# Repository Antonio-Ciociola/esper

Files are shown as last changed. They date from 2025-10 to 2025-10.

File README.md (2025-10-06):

# Esper

An esp32 based eurorack module.

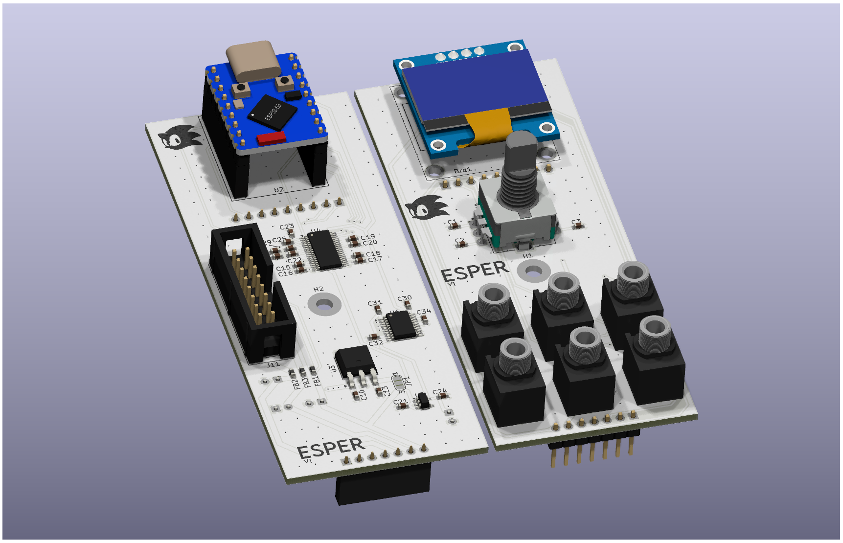
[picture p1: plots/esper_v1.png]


## Specifications

- 8HP width
- 4 CV inputs
- 2 Audio Outputs
- Oled Display with LVGL GUI
- Rotary Encoder with Push Button
- Esp32s3 has 2 cores, Bluetooth and Wifi support

## Photos





## Future Plans and Issues

- Better alternative to external adc for cv inputs
- Codec chip for both audio in and out, to allow for audio processing
- The esp32s3 floating point performance is not great

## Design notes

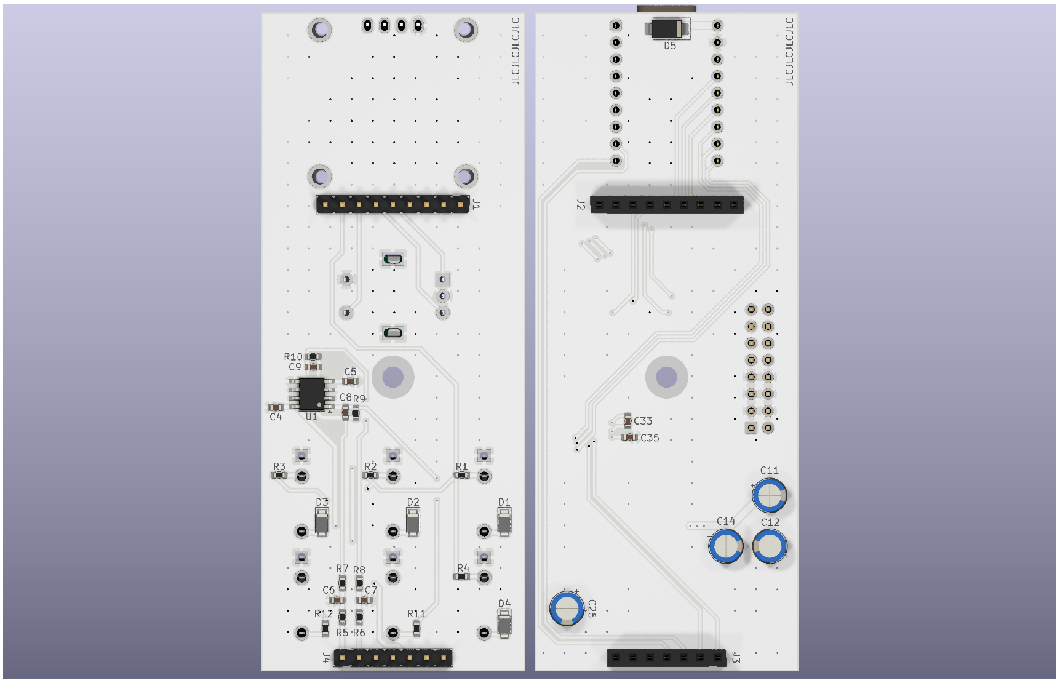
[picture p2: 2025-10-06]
plots/esper_v1_bottom.png

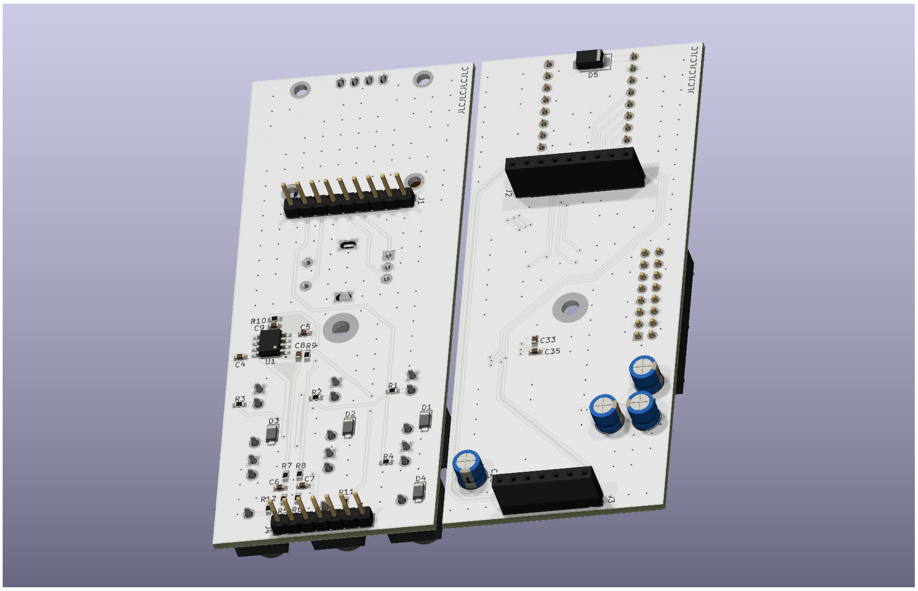
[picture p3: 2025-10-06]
plots/esper_v1_bottom_2.png

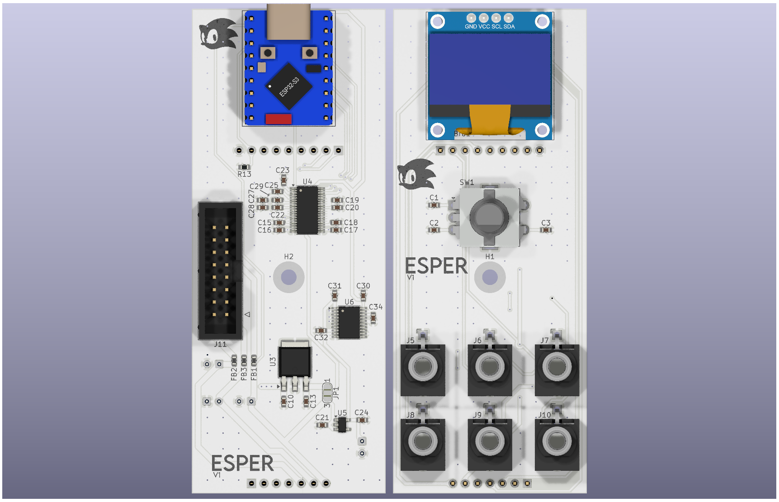
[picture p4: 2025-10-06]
plots/esper_v1_top.png

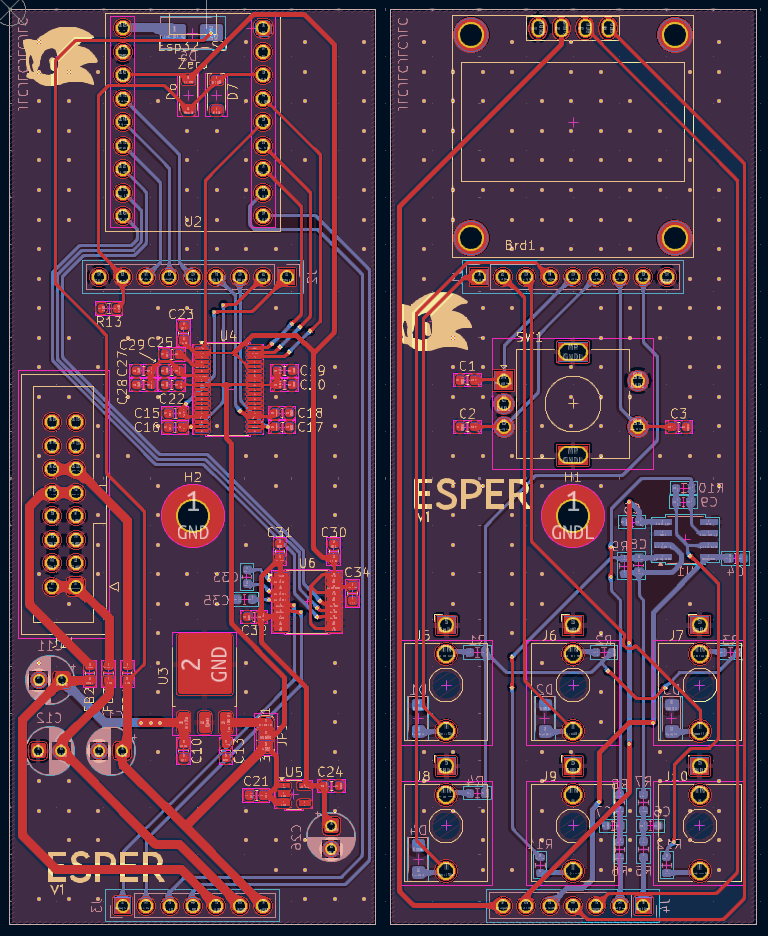
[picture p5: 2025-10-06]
plots/Pcb_screenshot.png

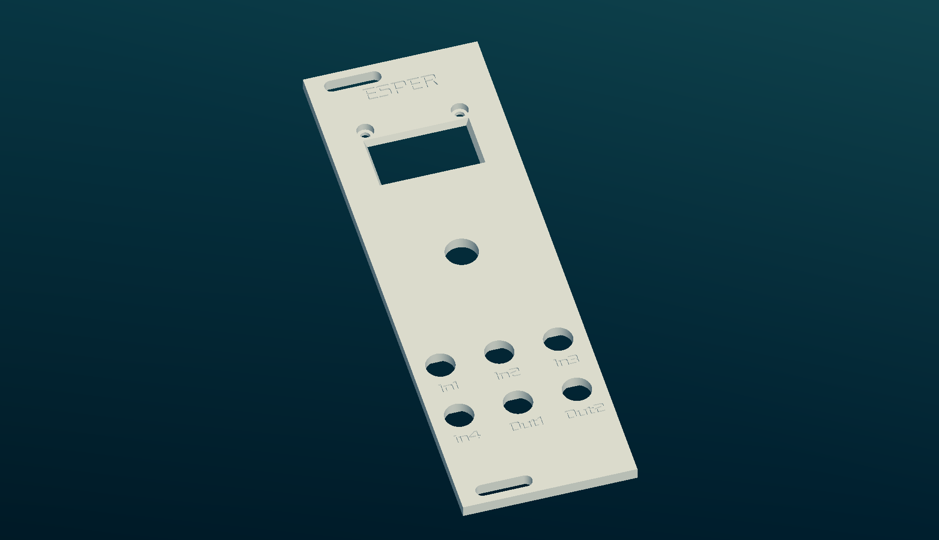
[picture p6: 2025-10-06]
panel/screenshot.png

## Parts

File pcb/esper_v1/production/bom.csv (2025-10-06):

Designator | Footprint | Quantity | Value | LCSC Part #
C10 | 0603 | 1 | 220n
C11, C12, C14, C26 | CP_Radial_D5.0mm_P2.50mm | 4 | 10u
C13, C21, C24, C30, C31, C32, C34 | 0603 | 7 | 100n
C15, C16, C17, C18 | 0603 | 4 | 1n
C19, C23, C25, C27, C28 | 0603 | 5 | 10u
C20, C22, C29 | 0603 | 3 | 1u
C33, C35 | 0603 | 2 | 2.2u
D5 | D_SMA | 1 | B340A
D6, D7 | D_SOD-123 | 2 | BAT43
FB1, FB2, FB3 | 0603 | 3 | BLM18R
J11 | IDC-Header_2x08_P2.54mm_Vertical | 1 | Conn_02x08_Odd_Even
J2 | PinSocket_1x09_P2.54mm_Vertical | 1 | m_in_Con
J3 | PinSocket_1x07_P2.54mm_Vertical | 1 | m_Out_Con
R13 | 0603 | 1 | _
U2 | Esp32-S3 Zero | 1 | ESP32_S3_zero
U3 | TO-252-3_TabPin2 | 1 | LM78M05_TO252
U4 | TSSOP-38_4.4x9.7mm_P0.5mm | 1 | ADS8688
U5 | SOT-23-5 | 1 | ME6211C33M5
U6 | TSSOP-20_4.4x6.5mm_P0.65mm | 1 | PCM5102A

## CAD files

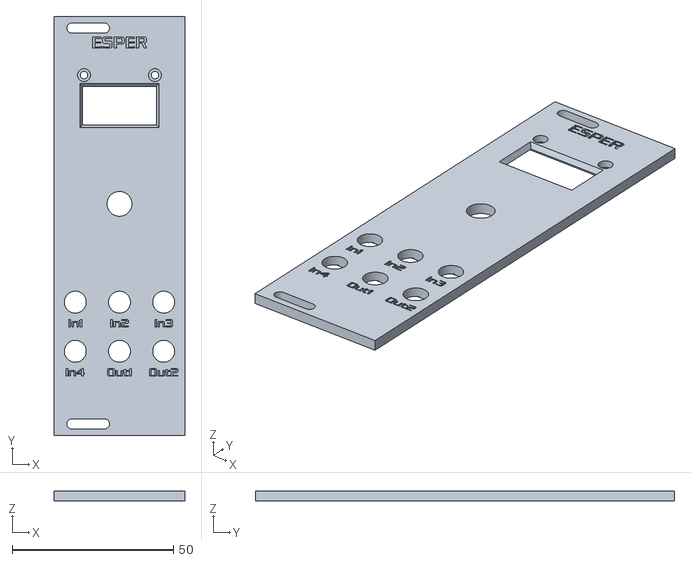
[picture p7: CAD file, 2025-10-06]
panel/esper.stl
40.6 x 130.0 x 3.00

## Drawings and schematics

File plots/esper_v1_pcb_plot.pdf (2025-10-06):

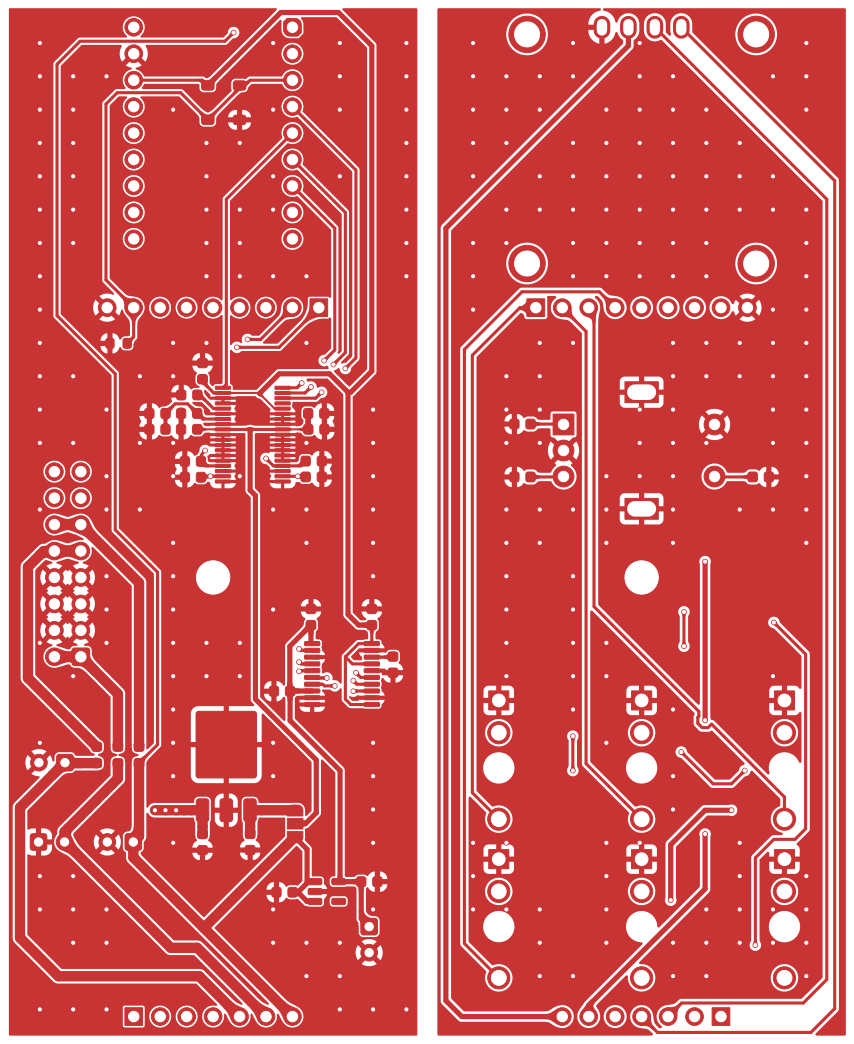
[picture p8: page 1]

Id: 1/9 Title: Esper File: esper_v1.kicad_pcb Sheet: Sonic803

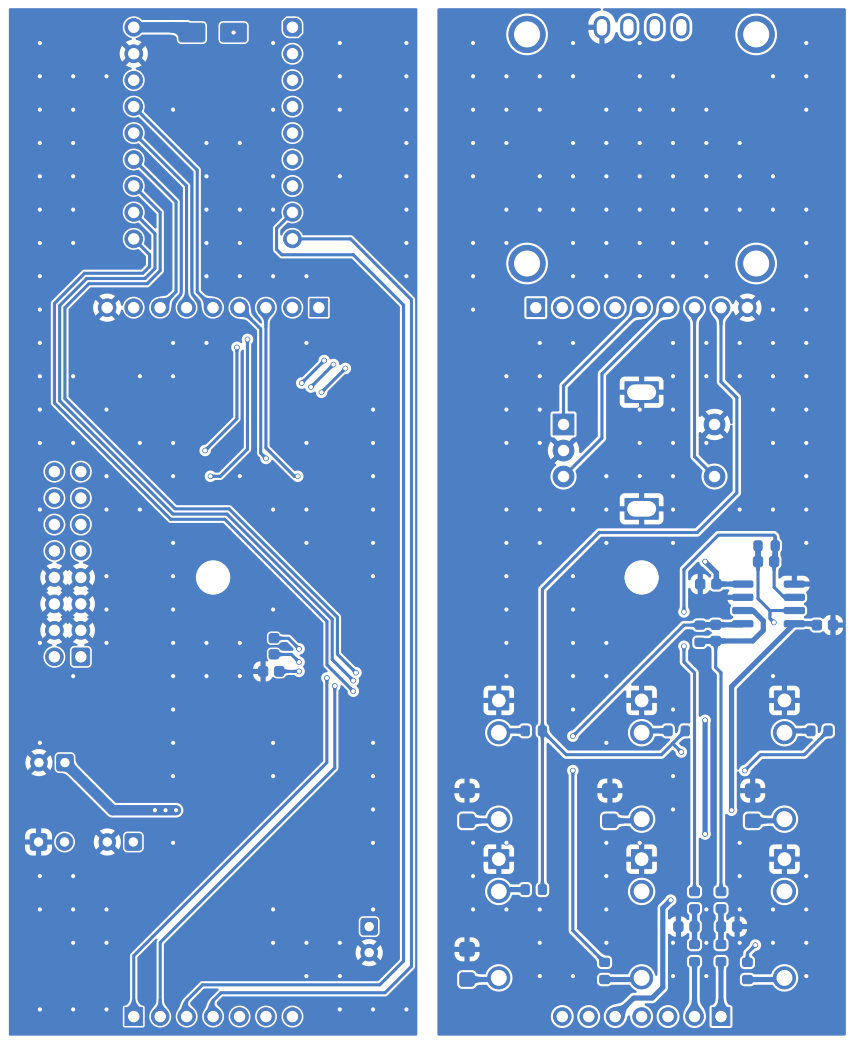
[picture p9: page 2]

Id: 2/9 Title: Esper File: esper_v1.kicad_pcb Sheet: Sonic803

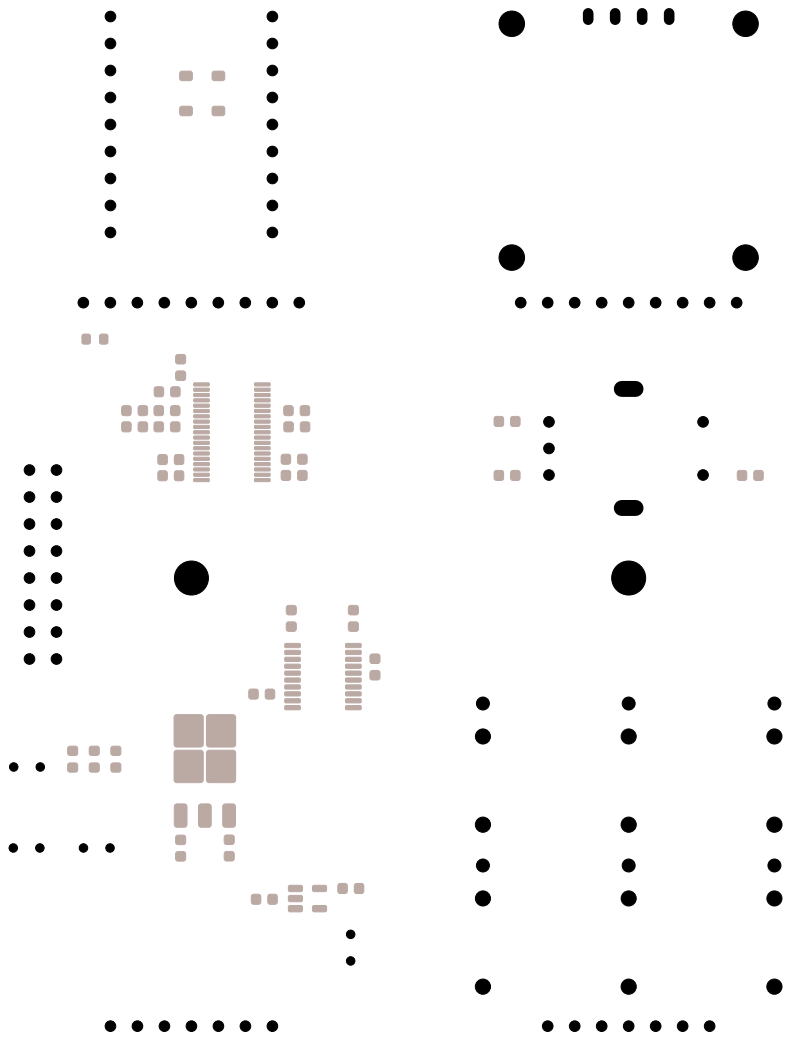
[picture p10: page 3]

Id: 3/9 Title: Esper File: esper_v1.kicad_pcb Sheet: Sonic803

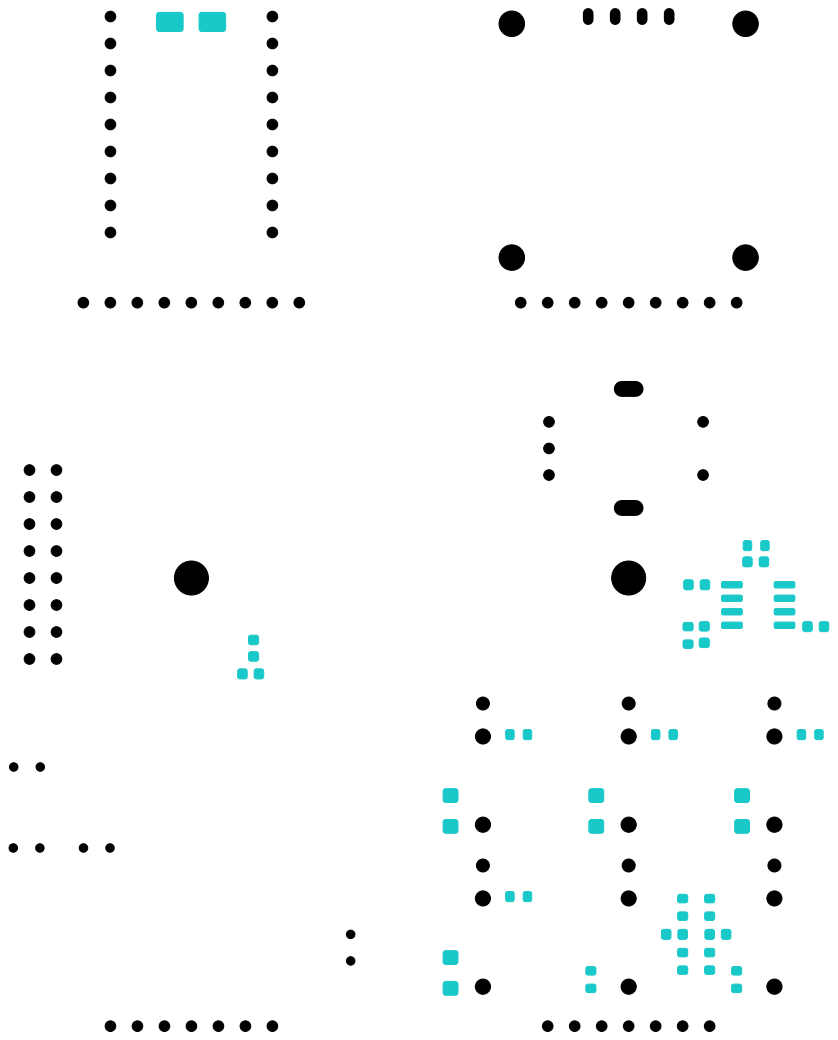
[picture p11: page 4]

Id: 4/9 Title: Esper File: esper_v1.kicad_pcb Sheet: Sonic803

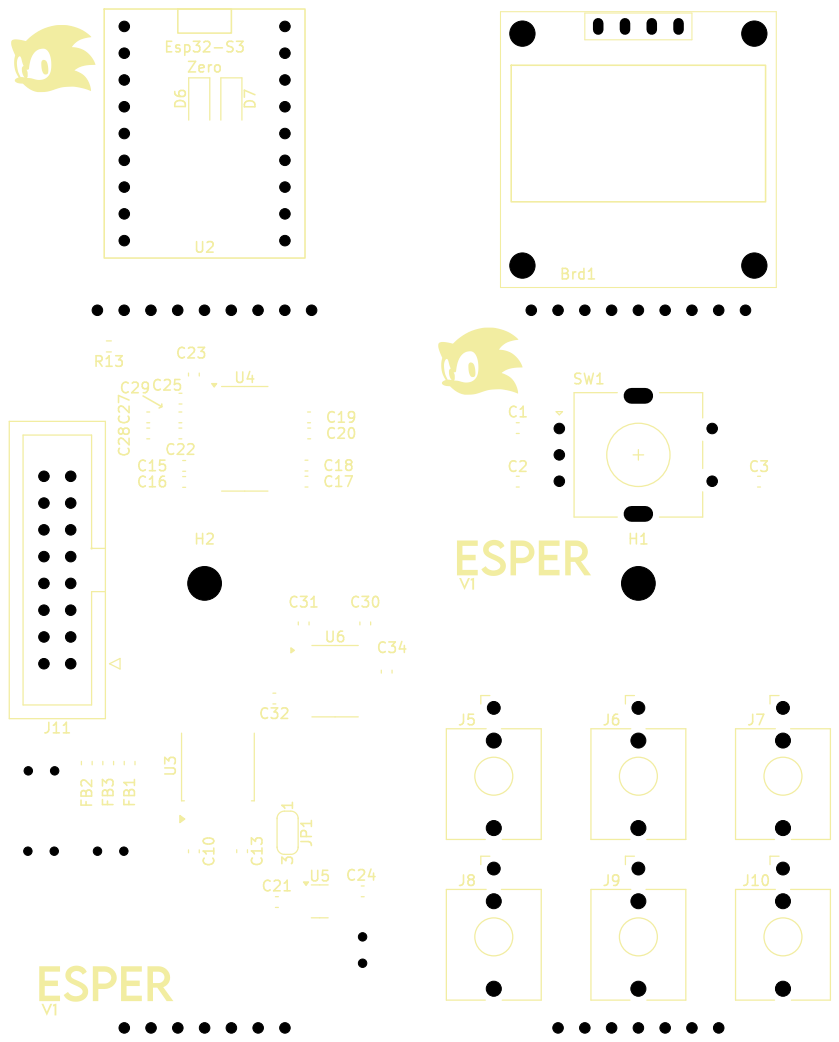
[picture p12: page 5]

Id: 5/9 Title: Esper File: esper_v1.kicad_pcb Sheet: Sonic803

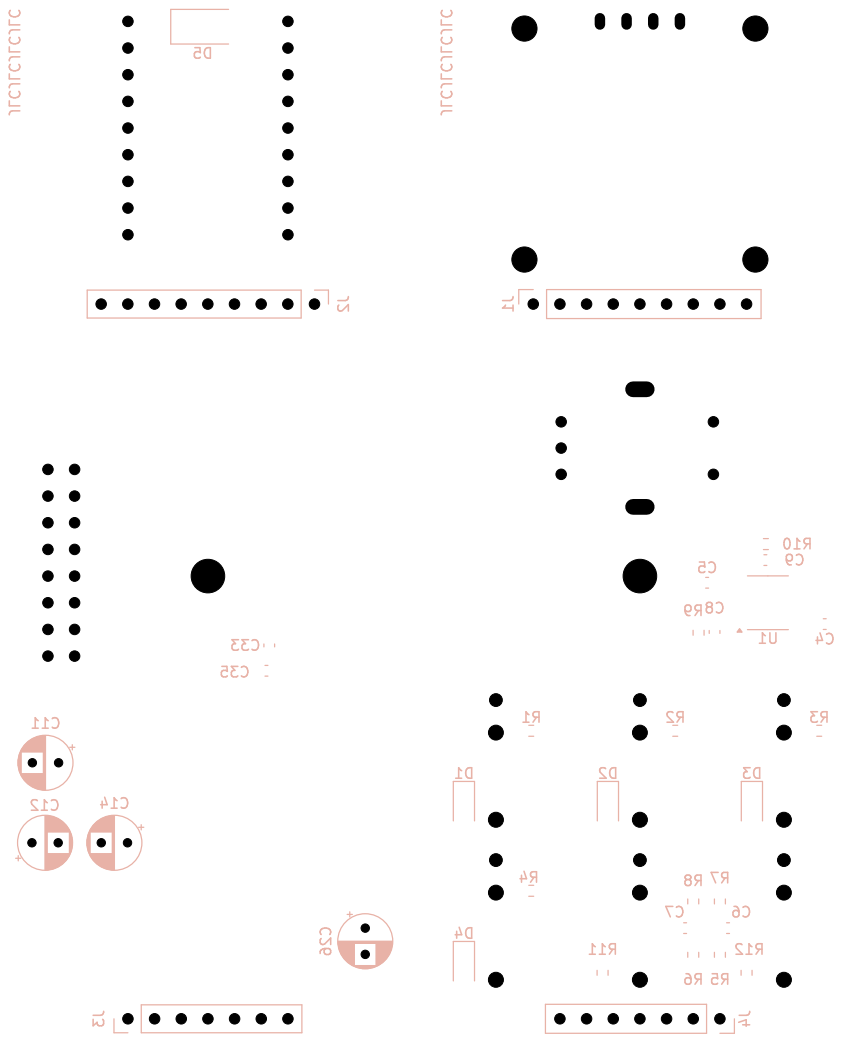
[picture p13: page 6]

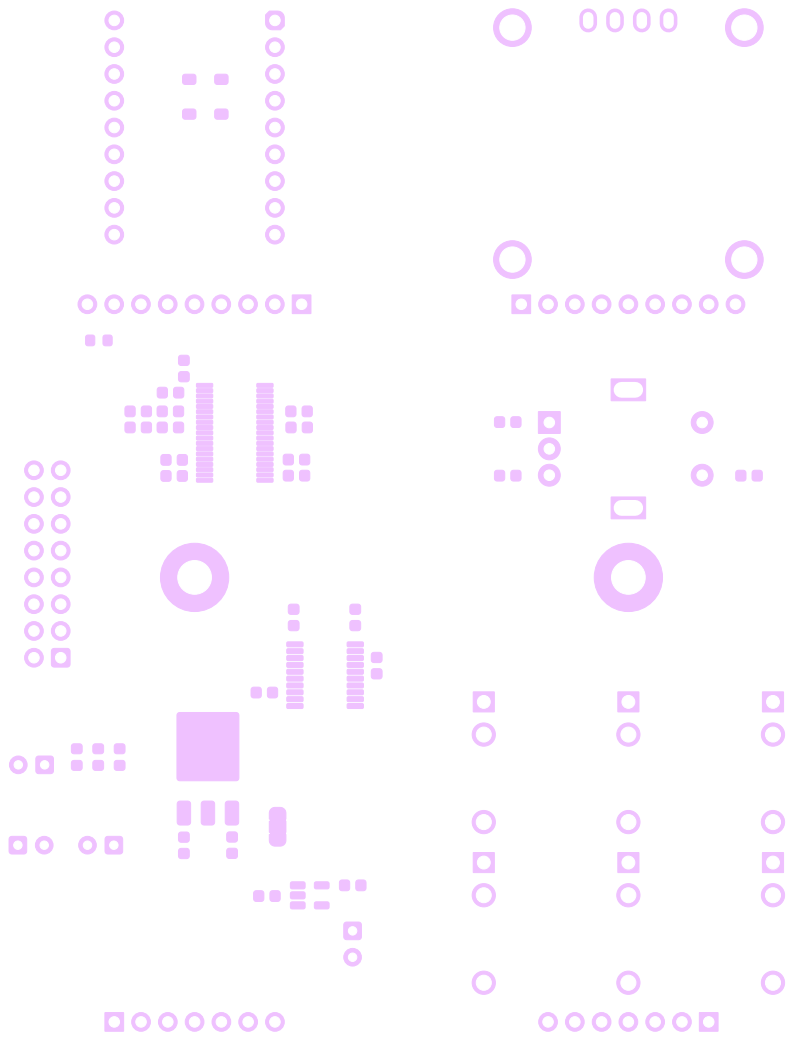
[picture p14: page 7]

Id: 7/9 Title: Esper File: esper_v1.kicad_pcb Sheet: Sonic803

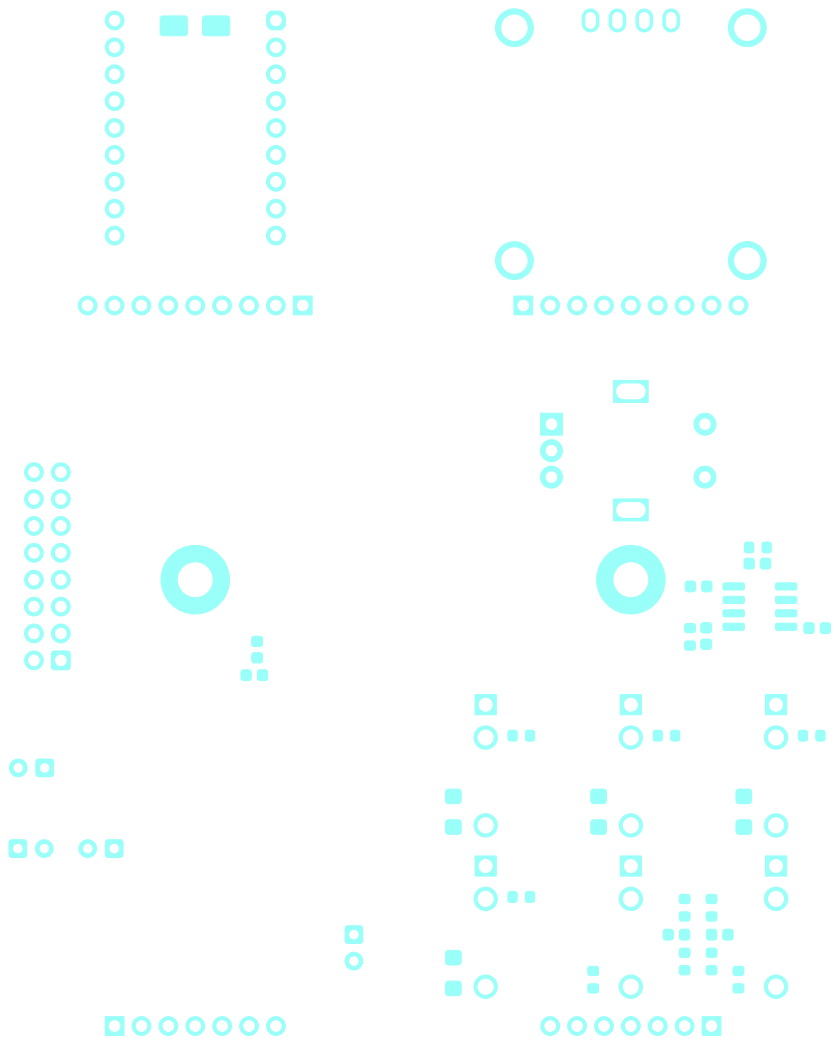
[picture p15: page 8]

Id: 8/9 Title: Esper File: esper_v1.kicad_pcb Sheet: Sonic803

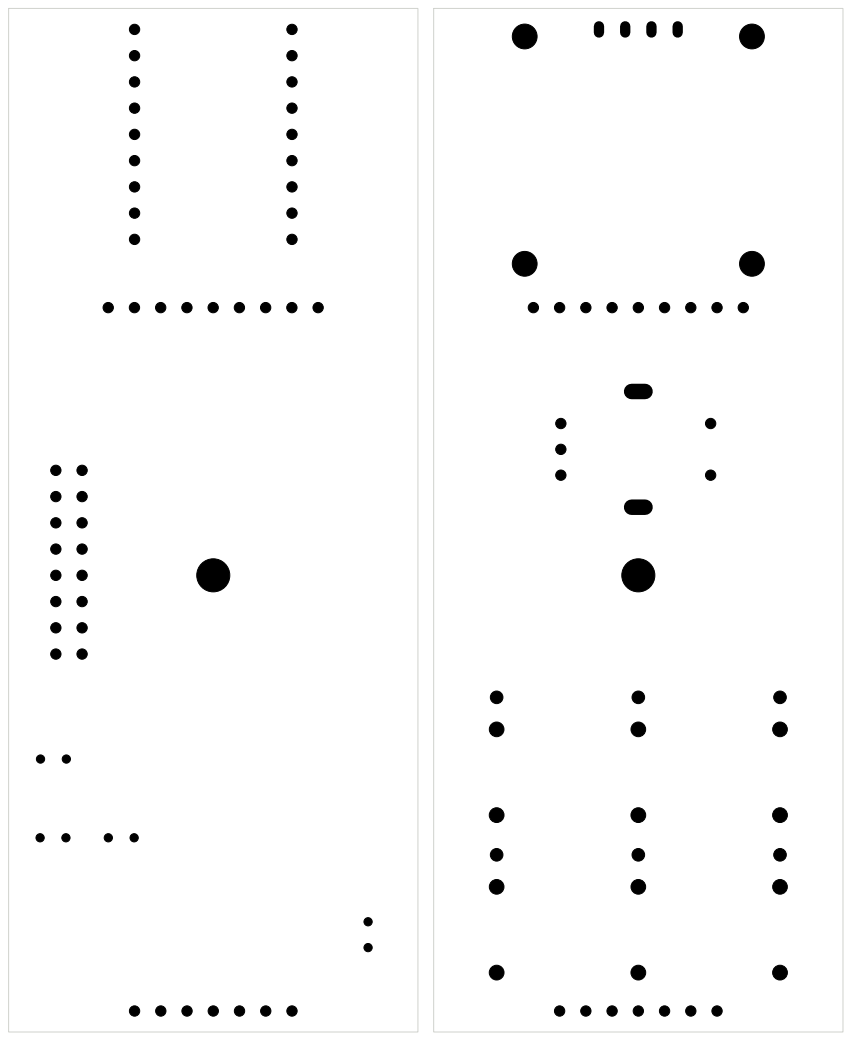
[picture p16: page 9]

Id: 9/9 Title: Esper File: esper_v1.kicad_pcb Sheet: Sonic803

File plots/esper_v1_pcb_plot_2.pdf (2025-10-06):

J8 U2 Esp32-S3 Zero C25 | U6
J9 C31 C29 | C17 R13 | C30 U4 C¹³ C22C23 1 | 2 | 3 | 4 | 5 | 6 1 | 2 | 3 | 4 | 5 | 6 ABCD | ABCD Date: 2025-05-13 KiCad | E.D.A. 9.0.4 Size: A4 | Rev: 1

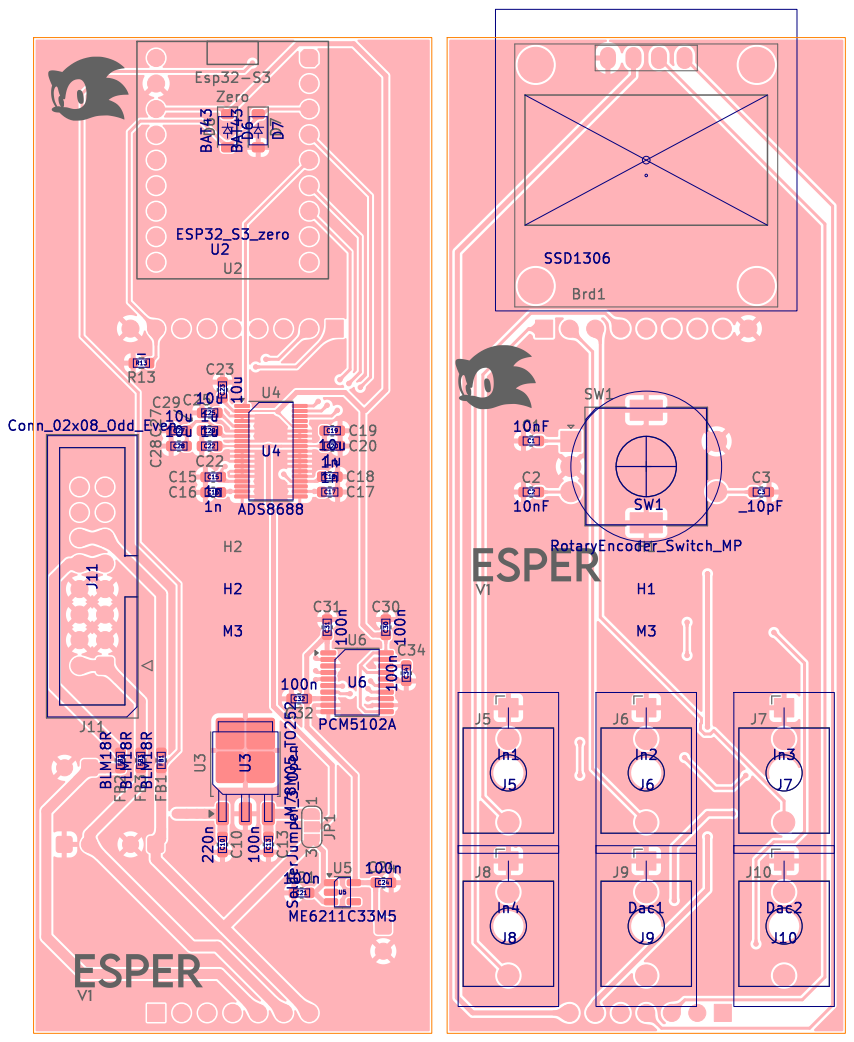
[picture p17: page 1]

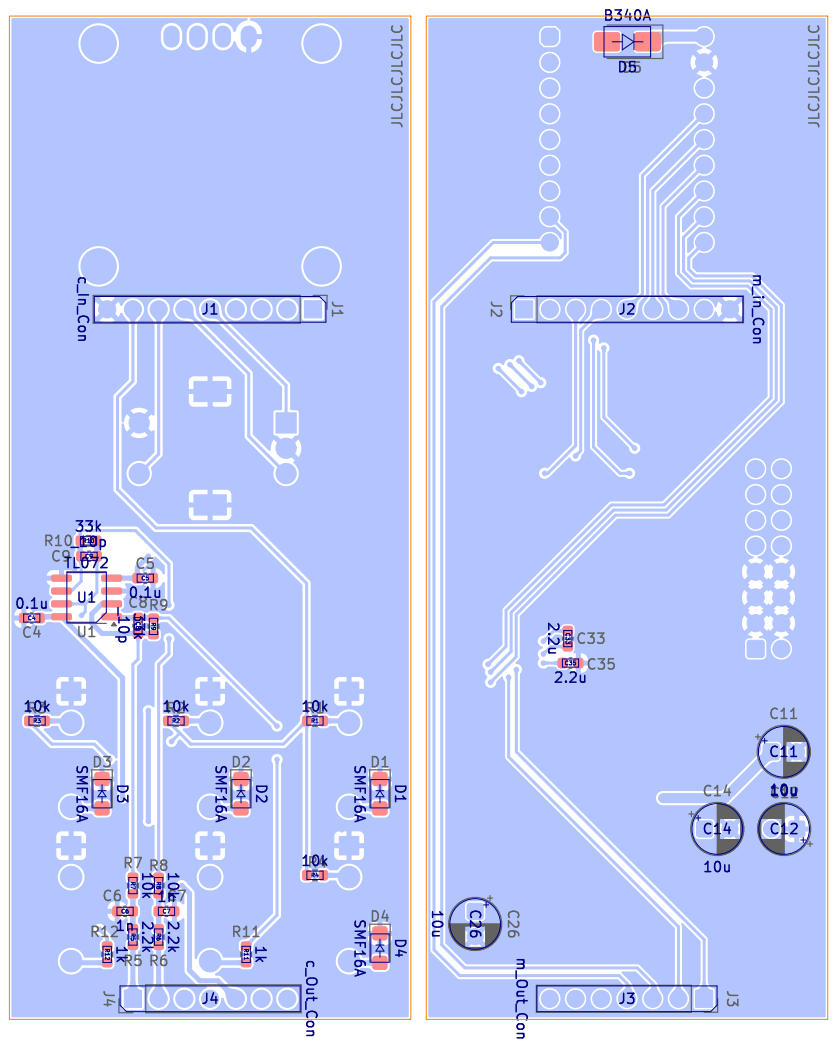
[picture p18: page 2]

JLCJLCJLCJLC JLCJLCJLCJLC J2 C7 R11 R1 C11 C14 C35 R9 D4 R10 C5 R12 C33 J3 D5 R4 C12 C9 C6 D1 R7 C4 D3 D2 R5C8 C26 U1 R2 J4 R6 R8 J1 R3 1 2 3 4 5 6 1 2 3 4 5 6 ABCD ABCD Date: 2025-05-13 KiCad E.D.A. 9.0.4 Size: A4 Rev: 1

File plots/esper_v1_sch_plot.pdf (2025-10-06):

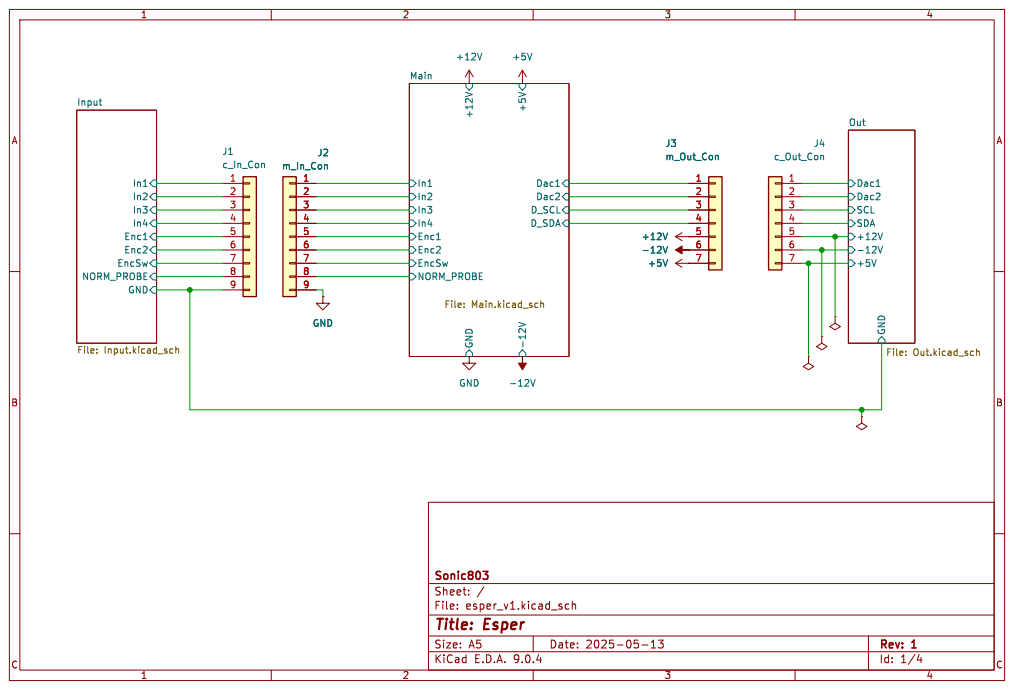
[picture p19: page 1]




2 VO 3 C10 220n GNDLH2 M3 +3.3V U2 ESP32_S3_zero GPIO1 15 GPIO2 14 GPIO3 13 GPIO4 12 GPIO5 11 GPIO6 10 RX 2 TX 1 VBus 18 GND 17 3V3 16 GPIO13 3 GPIO12 4 GPIO11 5 GPIO10 6 GPIO9 7 GPIO8 8 GPIO7 9 GNDL D5B340A U5 ME6211C33M5 V_{IN} 1 CE 3 V_{SS} 2 V_{OUT} 5 GNDL C24

9 OUTL 6 OUTR 7 CAPP 2 CAPM 4

8 AVDD 30 DVDD 34 DGND 33 SDO 36 SDI 1 SCLK 37 ~{CS} 38 DAISY 3 ~{RST/PD}2 ~{REFSEL}4 REFCAP 7 REFIO 5 REFGND 6 U4ADS8688

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

Id: 4/4 Title: Esper File: Main.kicad_sch Sheet: /Main/ Sonic803

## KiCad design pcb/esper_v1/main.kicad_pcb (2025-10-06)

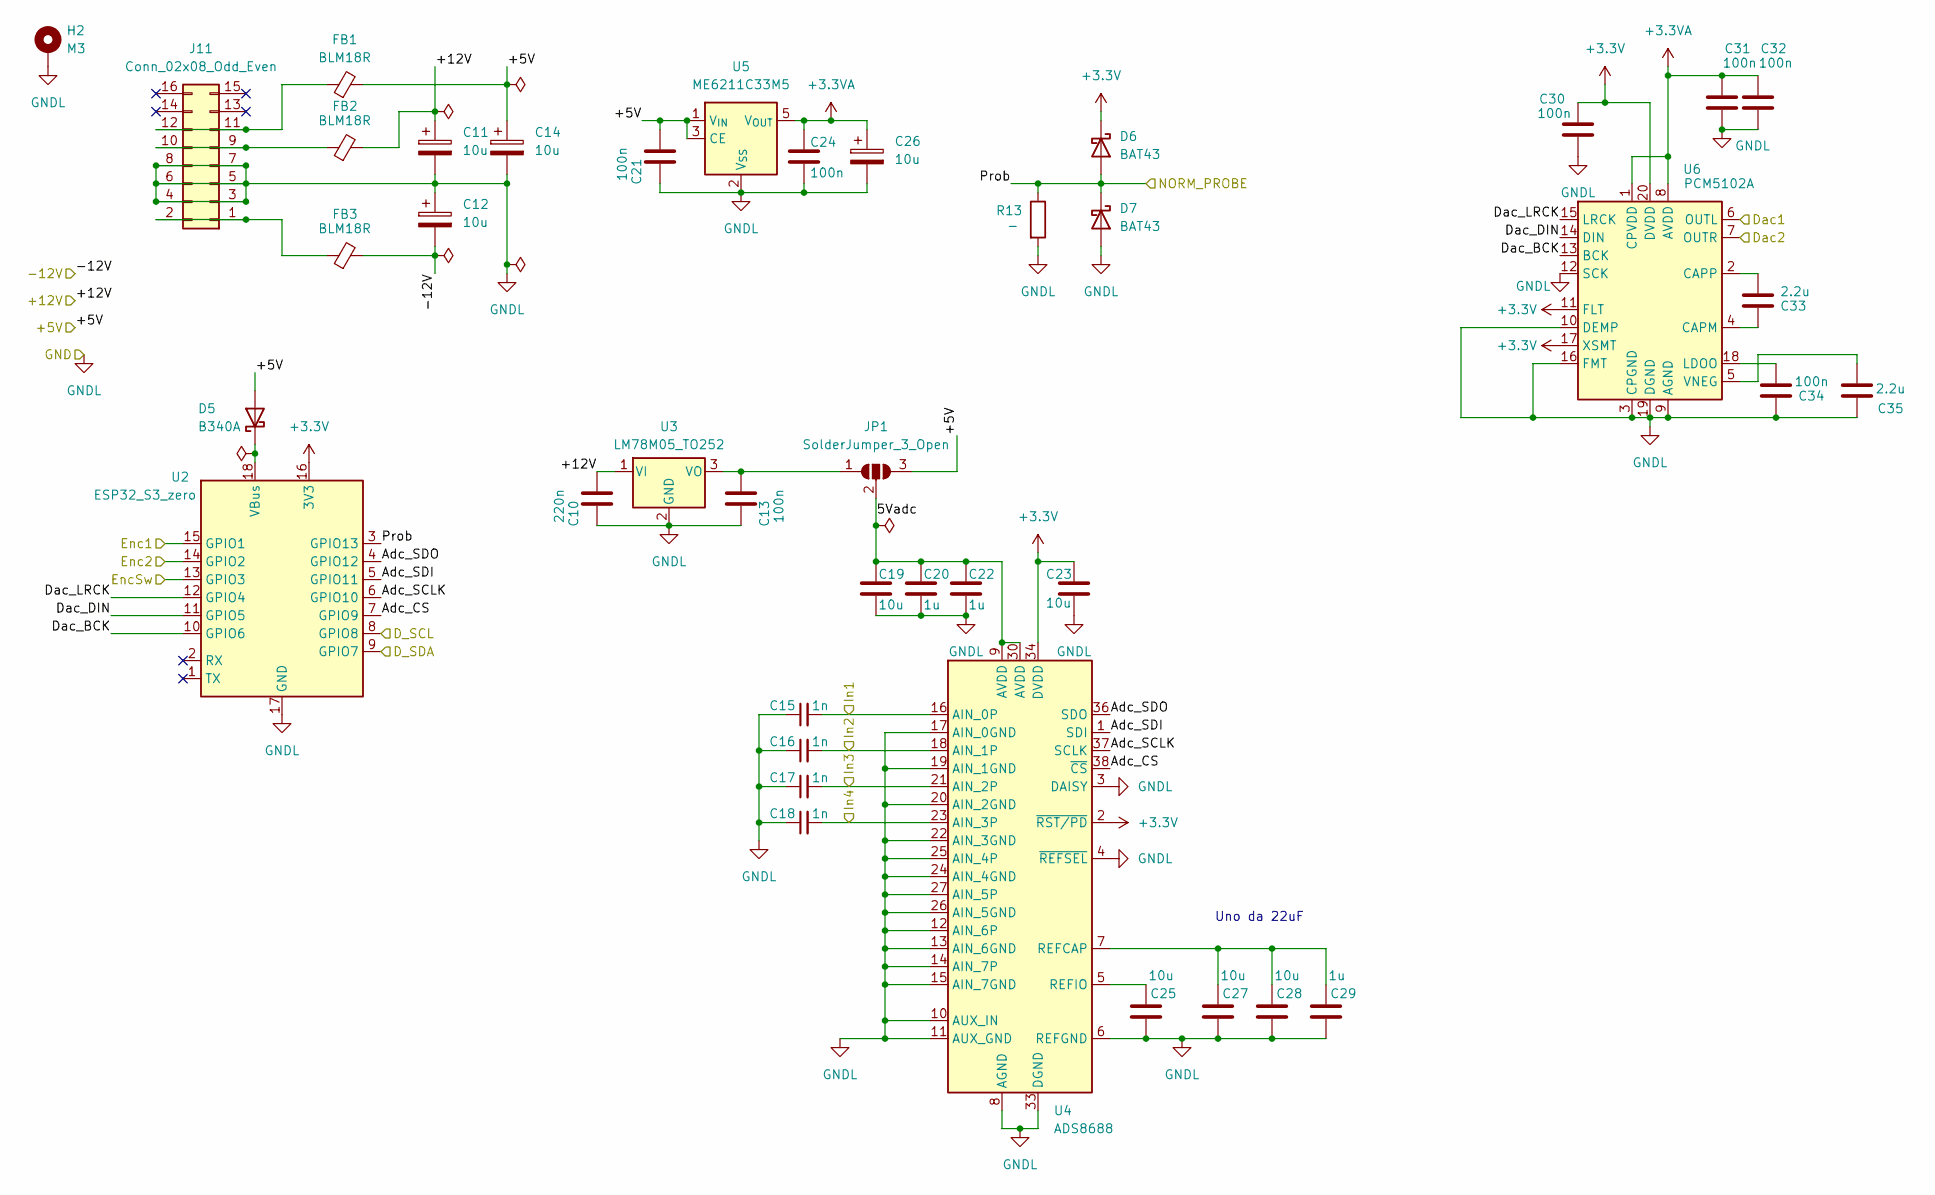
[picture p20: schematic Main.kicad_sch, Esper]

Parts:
C10: 220n; C_0603_1608Metric
C11, C12, C14, C26: 10u; CP_Radial_D5.0mm_P2.50mm
C13, C21, C24, C30, C31, C32, C34: 100n; C_0603_1608Metric
C15, C16, C17, C18: 1n; C_0603_1608Metric
C19, C23, C25, C27, C28: 10u; C_0603_1608Metric
C20, C22, C29: 1u; C_0603_1608Metric
C33, C35: 2.2u; C_0603_1608Metric
D5: B340A; D_SMA
D6, D7: BAT43; D_SOD-123
FB1, FB2, FB3: BLM18R; L_0603_1608Metric
H2: M3; MountingHole_3.2mm_M3_Pad
J11: Conn_02x08_Odd_Even; IDC-Header_2x08_P2.54mm_Vertical
JP1: SolderJumper_3_Open; SolderJumper-3_P1.3mm_Open_RoundedPad1.0x1.5mm_NumberLabels
R13: _; R_0603_1608Metric
U2: ESP32_S3_zero; Esp32-S3 Zero
U3: LM78M05_TO252; TO-252-3_TabPin2
U4: ADS8688; TSSOP-38_4.4x9.7mm_P0.5mm
U5: ME6211C33M5; SOT-23-5
U6: PCM5102A; TSSOP-20_4.4x6.5mm_P0.65mm

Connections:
+3.3V: C23.1, C30.1, D6.1 (K), U2.16 (3V3), U4.2 (~RST/PD), U4.34 (DVDD), U6.11 (FLT), U6.17 (XSMT), U6.20 (DVDD)
+3.3VA: C24.2, C26.1, C31.1, C32.1, U5.5 (V_{OUT}), U6.1 (CPVDD), U6.8 (AVDD)
+5V: C14.1, C21.1, D5.2 (A), FB1.2, JP1.3 (B), U5.1 (V_{IN}), U5.3 (CE); also elsewhere on the board
+12V: C10.1, C11.1, FB2.2, U3.1 (VI); also elsewhere on the board
-12V: C12.2, FB3.2; also elsewhere on the board
/Main/5Vadc: C19.1, C20.1, C22.1, JP1.2 (C), U4.9 (AVDD), U4.30 (AVDD)
/Main/Adc_CS: U2.7 (GPIO9), U4.38 (~CS)
/Main/Adc_SCLK: U2.6 (GPIO10), U4.37 (SCLK)
/Main/Adc_SDI: U2.5 (GPIO11), U4.1 (SDI)
/Main/Adc_SDO: U2.4 (GPIO12), U4.36 (SDO)
/Main/D_SCL: U2.8 (GPIO8); also elsewhere on the board
/Main/D_SDA: U2.9 (GPIO7); also elsewhere on the board
/Main/Dac1: U6.6 (OUTL); also elsewhere on the board
/Main/Dac2: U6.7 (OUTR); also elsewhere on the board
/Main/Dac_BCK: U2.10 (GPIO6), U6.13 (BCK)
/Main/Dac_DIN: U2.11 (GPIO5), U6.14 (DIN)
/Main/Dac_LRCK: U2.12 (GPIO4), U6.15 (LRCK)
/Main/Enc1: U2.15 (GPIO1); also elsewhere on the board
/Main/Enc2: U2.14 (GPIO2); also elsewhere on the board
/Main/EncSw: U2.13 (GPIO3); also elsewhere on the board
/Main/In1: C15.2, U4.16 (AIN_0P); also elsewhere on the board
/Main/In2: C16.2, U4.18 (AIN_1P); also elsewhere on the board
/Main/In3: C17.2, U4.21 (AIN_2P); also elsewhere on the board
/Main/In4: C18.2, U4.23 (AIN_3P); also elsewhere on the board
/Main/Prob: D6.2 (A), D7.1 (K), R13.1, U2.3 (GPIO13); also elsewhere on the board
GND: C10.2, C11.2, C12.1, C13.2, C14.2, C15.1, C16.1, C17.1, C18.1, C19.2, C20.2, C21.2, C22.2, C23.2, C24.1, C25.2, C26.2, C27.2, C28.2, C29.2, C30.2, C31.2, C32.2, C34.2, C35.2, D7.2 (A), H2.1, J11.3, J11.4, J11.5, J11.6, J11.7, J11.8, R13.2, U2.17 (GND), U3.2 (GND), U4.3 (DAISY), U4.4 (~REFSEL), U4.6 (REFGND), U4.8 (AGND), U4.10 (AUX_IN), U4.11 (AUX_GND), U4.12 (AIN_6P), U4.13 (AIN_6GND), U4.14 (AIN_7P), U4.15 (AIN_7GND), U4.17 (AIN_0GND), U4.19 (AIN_1GND), U4.20 (AIN_2GND), U4.22 (AIN_3GND), U4.24 (AIN_4GND), U4.25 (AIN_4P), U4.26 (AIN_5GND), U4.27 (AIN_5P), U4.28 (AGND), U4.29 (AGND), U4.31 (AGND), U4.32 (AGND), U4.33 (DGND), U5.2 (V_{SS}), U6.3 (CPGND), U6.9 (AGND), U6.10 (DEMP), U6.12 (SCK), U6.16 (FMT), U6.19 (DGND); also elsewhere on the board
unnamed: D5.1 (K), U2.18 (VBus)
unnamed: FB3.1, J11.1, J11.2
unnamed: FB2.1, J11.9, J11.10
unnamed: FB1.1, J11.11, J11.12
unnamed: C13.1, JP1.1 (A), U3.3 (VO)
unnamed: C27.1, C28.1, C29.1, U4.7 (REFCAP)
unnamed: C25.1, U4.5 (REFIO)
unnamed: C33.2, U6.4 (CAPM)
unnamed: C33.1, U6.2 (CAPP)
unnamed: C34.1, U6.18 (LDOO)
unnamed: C35.1, U6.5 (VNEG)

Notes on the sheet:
Uno da 22uF

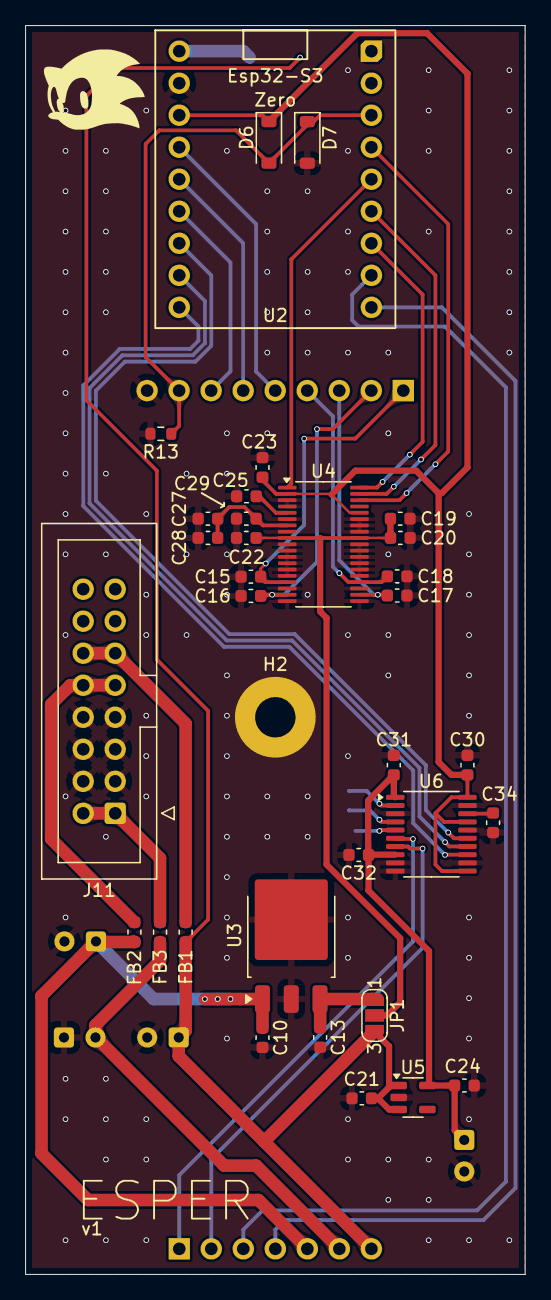
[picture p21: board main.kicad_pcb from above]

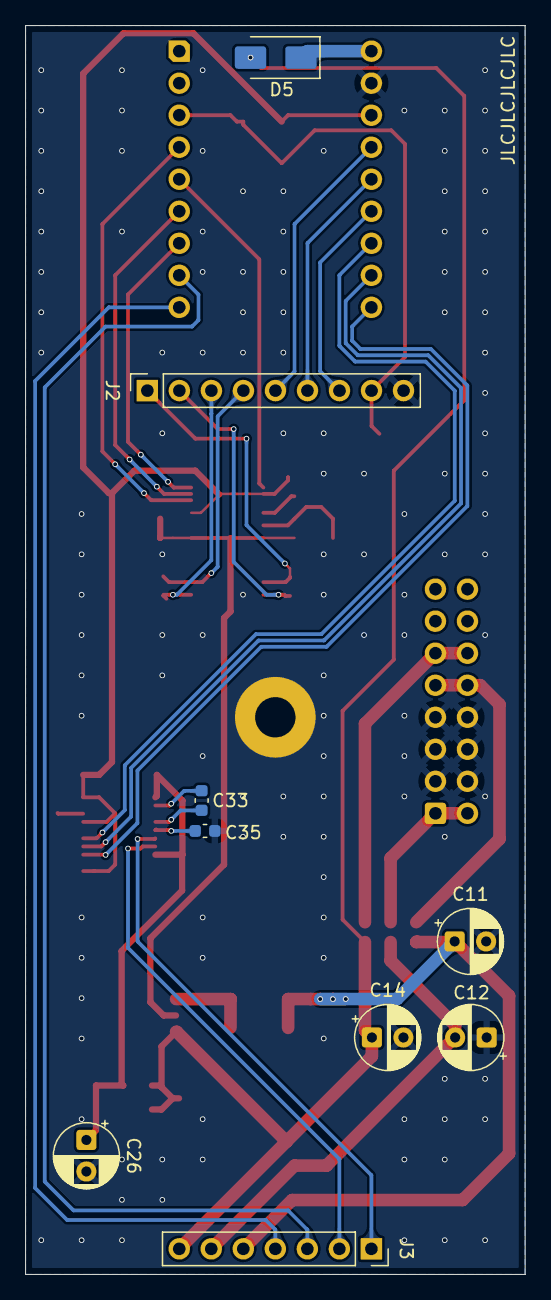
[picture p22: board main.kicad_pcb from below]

Board: 2 copper layers, 39.6 x 99.1 mm, 43 parts (9 on the bottom side), 37 nets.

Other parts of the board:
J2: m_in_Con; PinSocket_1x09_P2.54mm_Vertical
J3: m_Out_Con; PinSocket_1x07_P2.54mm_Vertical

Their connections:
+5V: J3.7; also elsewhere on the board
+12V: J3.5; also elsewhere on the board
-12V: J3.6; also elsewhere on the board
/Main/D_SCL: J3.3; also elsewhere on the board
/Main/D_SDA: J3.4; also elsewhere on the board
/Main/Dac1: J3.1; also elsewhere on the board
/Main/Dac2: J3.2; also elsewhere on the board
/Main/Enc1: J2.5; also elsewhere on the board
/Main/Enc2: J2.6; also elsewhere on the board
/Main/EncSw: J2.7; also elsewhere on the board
/Main/In1: J2.1; also elsewhere on the board
/Main/In2: J2.2; also elsewhere on the board
/Main/In3: J2.3; also elsewhere on the board
/Main/In4: J2.4; also elsewhere on the board
/Main/Prob: J2.8; also elsewhere on the board
GND: J2.9; also elsewhere on the board

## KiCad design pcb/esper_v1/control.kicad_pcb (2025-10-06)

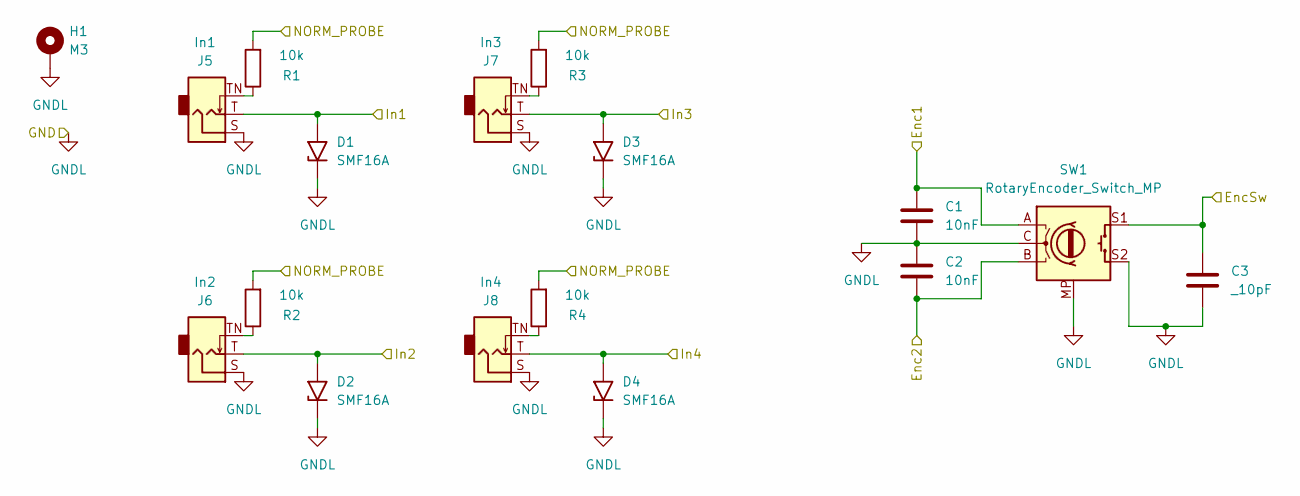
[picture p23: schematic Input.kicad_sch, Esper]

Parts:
C1, C2: 10nF; C_0603_1608Metric
C3: _10pF; C_0603_1608Metric
D1, D2, D3, D4: SMF16A; D_SMF
H1: M3; MountingHole_3.2mm_M3_Pad
J5: In1; Jack
J6: In2; Jack
J7: In3; Jack
J8: In4; Jack
R1, R2, R3, R4: 10k; R_0603_1608Metric
SW1: RotaryEncoder_Switch_MP; RotaryEncoder_Switch

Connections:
/Input/Enc1: C1.1, SW1.A; also elsewhere on the board
/Input/Enc2: C2.2, SW1.B; also elsewhere on the board
/Input/EncSw: C3.1, SW1.S1; also elsewhere on the board
/Input/In1: D1.2 (A2), J5.T; also elsewhere on the board
/Input/In2: D2.2 (A2), J6.T; also elsewhere on the board
/Input/In3: D3.2 (A2), J7.T; also elsewhere on the board
/Input/In4: D4.2 (A2), J8.T; also elsewhere on the board
/Input/NORM_PROBE: R1.2, R2.2, R3.2, R4.2; also elsewhere on the board
GNDL: C1.2, C2.1, C3.2, D1.1 (A1), D2.1 (A1), D3.1 (A1), D4.1 (A1), H1.1, J5.S, J6.S, J7.S, J8.S, SW1.C, SW1.MP, SW1.S2; also elsewhere on the board
unnamed: J5.TN, R1.1
unnamed: J6.TN, R2.1
unnamed: J7.TN, R3.1
unnamed: J8.TN, R4.1

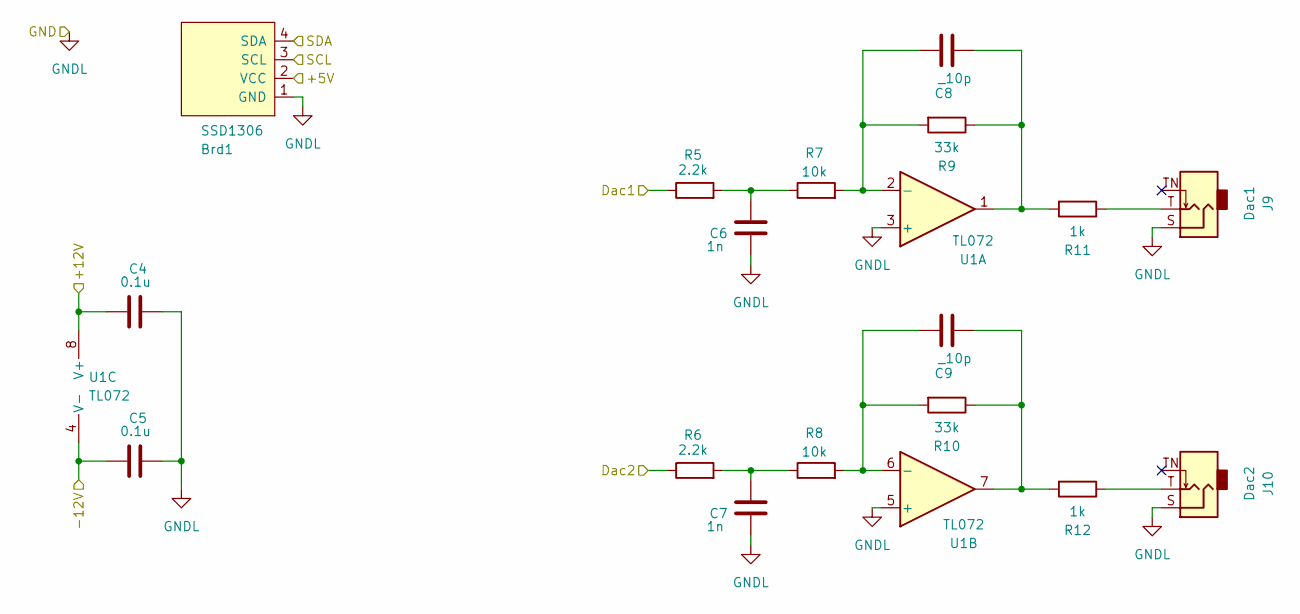
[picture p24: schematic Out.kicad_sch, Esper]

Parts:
Brd1: SSD1306; 128x64OLED
C4, C5: 0.1u; C_0603_1608Metric
C6, C7: 1n; C_0603_1608Metric
C8, C9: _10p; C_0603_1608Metric
J9: Dac1; Jack
J10: Dac2; Jack
R5, R6: 2.2k; R_0603_1608Metric
R7, R8: 10k; R_0603_1608Metric
R9, R10: 33k; R_0603_1608Metric
R11, R12: 1k; R_0603_1608Metric
U1: TL072; SOIC-8_3.9x4.9mm_P1.27mm

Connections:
/Out/+5V: Brd1.2 (VCC); also elsewhere on the board
/Out/+12V: C4.1, U1.8 (V+); also elsewhere on the board
/Out/-12V: C5.1, U1.4 (V-); also elsewhere on the board
/Out/Dac1: R5.1; also elsewhere on the board
/Out/Dac2: R6.1; also elsewhere on the board
/Out/SCL: Brd1.3 (SCL); also elsewhere on the board
/Out/SDA: Brd1.4 (SDA); also elsewhere on the board
GNDL: Brd1.1 (GND), C4.2, C5.2, C6.1, C7.1, J9.S, J10.S, U1.3 (+), U1.5 (+); also elsewhere on the board
unnamed: C6.2, R5.2, R7.1
unnamed: C7.2, R6.2, R8.1
unnamed: C8.1, R9.1, R11.2, U1.1
unnamed: C9.1, R10.1, R12.2, U1.7
unnamed: J9.T, R11.1
unnamed: J10.T, R12.1
unnamed: C8.2, R7.2, R9.2, U1.2 (-)
unnamed: C9.2, R8.2, R10.2, U1.6 (-)

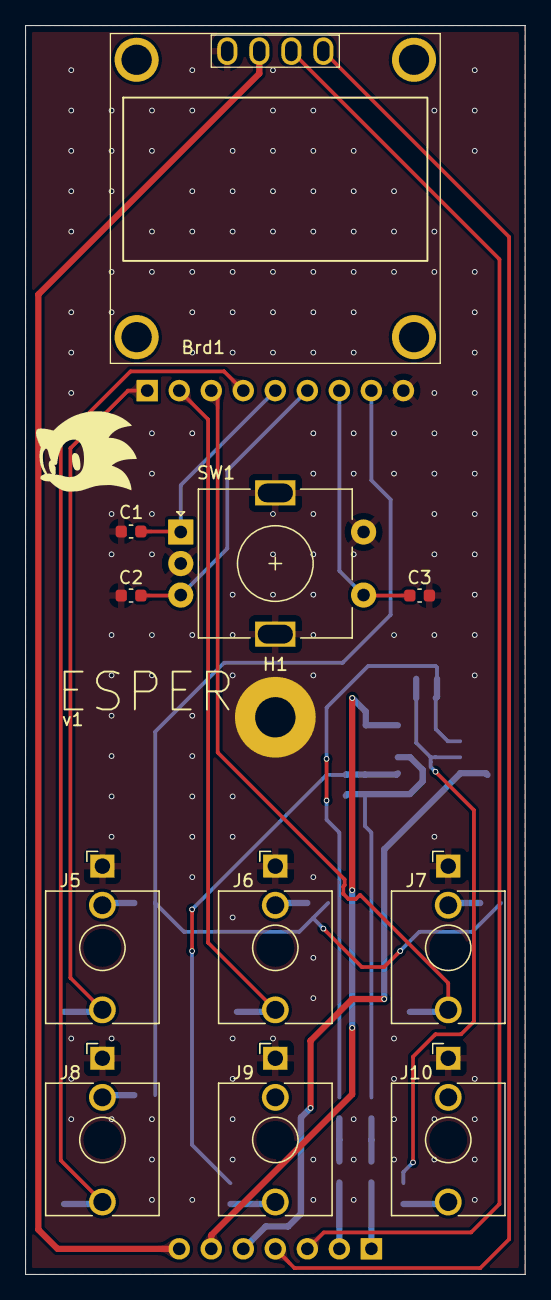
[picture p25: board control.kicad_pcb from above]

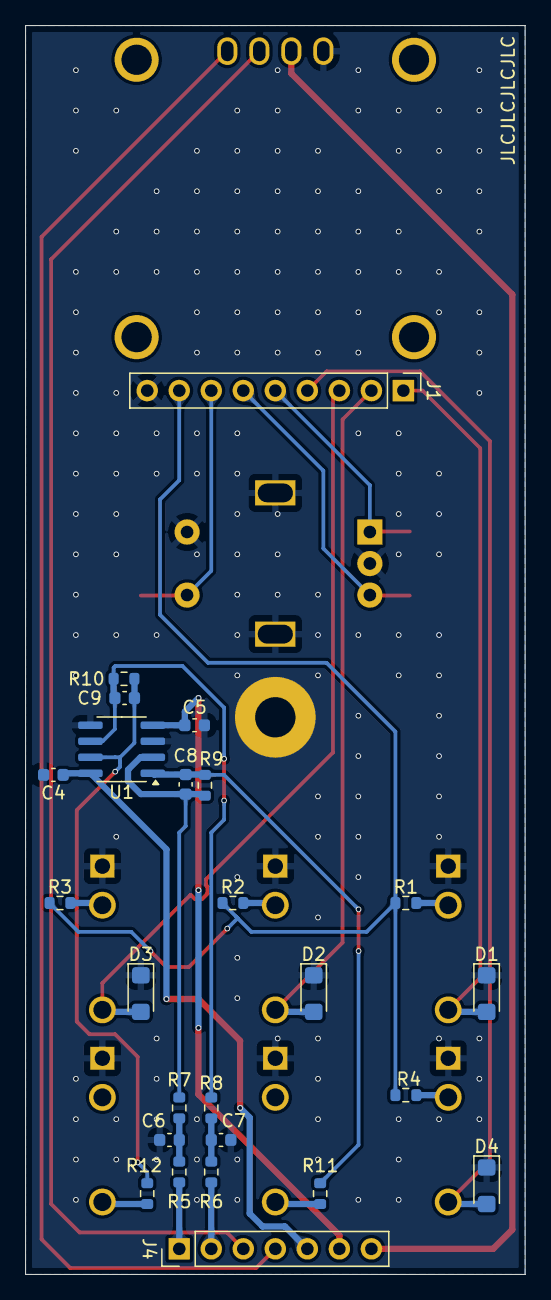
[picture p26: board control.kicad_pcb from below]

Board: 2 copper layers, 39.6 x 99.1 mm, 37 parts (25 on the bottom side), 28 nets.

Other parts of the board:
J1: c_In_Con; PinHeader_1x09_P2.54mm_Vertical
J4: c_Out_Con; PinHeader_1x07_P2.54mm_Vertical

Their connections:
/Input/Enc1: J1.5; also elsewhere on the board
/Input/Enc2: J1.6; also elsewhere on the board
/Input/EncSw: J1.7; also elsewhere on the board
/Input/In1: J1.1; also elsewhere on the board
/Input/In2: J1.2; also elsewhere on the board
/Input/In3: J1.3; also elsewhere on the board
/Input/In4: J1.4; also elsewhere on the board
/Input/NORM_PROBE: J1.8; also elsewhere on the board
/Out/+5V: J4.7; also elsewhere on the board
/Out/+12V: J4.5; also elsewhere on the board
/Out/-12V: J4.6; also elsewhere on the board
/Out/Dac1: J4.1; also elsewhere on the board
/Out/Dac2: J4.2; also elsewhere on the board
/Out/SCL: J4.3; also elsewhere on the board
/Out/SDA: J4.4; also elsewhere on the board
GNDL: J1.9; also elsewhere on the board

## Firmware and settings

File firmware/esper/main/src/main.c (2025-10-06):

#include "freertos/FreeRTOS.h"
#include "esp_log.h"

#include "peripherals/display/display.h"
#include "peripherals/encoder/encoder.h"
#include "peripherals/digital/digital.h"
#include "peripherals/probe/probe.h"
#include "peripherals/lvgl/lvgl.h"
#include "peripherals/i2s/i2s.h"
#include "peripherals/adcSpi/adcSpi.h"
#include "peripherals/adc/testadc.h"

#include "utils/benchmark.h"
#include "utils/i2cscan.h"

#include "update.h"
#include "graphic.h"

static const char *TAG = "espvco";

void app_main(void)
{
    vTaskDelay(pdMS_TO_TICKS(2000));

    ESP_LOGI(TAG, "Main running on core %d", xPortGetCoreID());

    configDisplay();
    configEncoder();
    configLvgl();
    configDigital();
    configProbe();
    configAdcSpi();
    startGraphic();
    configI2s();
    configUpdate();

    // ESP_LOGI("MEM", "Free heap size: %" PRIu32 " KB", esp_get_free_heap_size() / 1024);
    // ESP_LOGI("MEM", "Free DRAM: %zu KB", heap_caps_get_free_size(MALLOC_CAP_8BIT) / 1024);
    // ESP_LOGI("MEM", "Free IRAM: %zu KB", heap_caps_get_free_size(MALLOC_CAP_EXEC) / 1024);
    // ESP_LOGI("MEM", "Free PSRAM: %zu KB", heap_caps_get_free_size(MALLOC_CAP_SPIRAM) / 1024);

    while (1)
    {
        // Make it non blocking
        runGraphic();
        vTaskDelay(pdMS_TO_TICKS(20));
    }

    // i2cscan(8, 7);
}
    

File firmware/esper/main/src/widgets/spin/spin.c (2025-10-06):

/**
 * @file spin.c
 *
 */

/*********************
 *      INCLUDES
 *********************/
#include "spin_private.h"
#include "core/lv_obj_class_private.h"

#include "misc/lv_assert.h"
#include "indev/lv_indev.h"
#include "stdlib/lv_string.h"

#include "defines.h"

#include "esp_log.h"

/*********************
 *      DEFINES
 *********************/
#define MY_CLASS (&spin_class)
#define SPIN_MAX_DIGIT_COUNT_WITH_8BYTES (SPIN_MAX_DIGIT_COUNT + 8U)
#define SPIN_MAX_DIGIT_COUNT_WITH_4BYTES (SPIN_MAX_DIGIT_COUNT + 4U)

/**********************
 *      TYPEDEFS
 **********************/

typedef struct _spin_t spin_t;

/**********************
 *  STATIC PROTOTYPES
 **********************/

static void spin_constructor(const lv_obj_class_t *class_p, lv_obj_t *obj);
static void spin_event(const lv_obj_class_t *class_p, lv_event_t *e);
static void spin_updatevalue(lv_obj_t *obj);

/**********************
 *  STATIC VARIABLES
 **********************/
const lv_obj_class_t spin_class = {
    .constructor_cb = spin_constructor,
    .event_cb = spin_event,
    .width_def = LV_DPI_DEF,
    .instance_size = sizeof(spin_t),
    .editable = LV_OBJ_CLASS_EDITABLE_TRUE,
    .base_class = &usr_textarea_class,
    .name = "spinbox",
};
/**********************
 *      MACROS
 **********************/

/**********************
 *   GLOBAL FUNCTIONS
 **********************/

lv_obj_t *spin_create(lv_obj_t *parent)
{
    LV_LOG_INFO("begin");
    lv_obj_t *obj = lv_obj_class_create_obj(MY_CLASS, parent);
    lv_obj_class_init_obj(obj);
    return obj;
}

/*=====================
 * Setter functions
 *====================*/

void spin_set_value(lv_obj_t *obj, int32_t v)
{
    LV_ASSERT_OBJ(obj, MY_CLASS);
    spin_t *spinbox = (spin_t *)obj;

    if (v > spinbox->range_max)
        v = spinbox->range_max;
    if (v < spinbox->range_min)
        v = spinbox->range_min;

    *spinbox->value = v;

    spin_updatevalue(obj);
}

void spin_set_value_p(lv_obj_t *obj, int32_t *v)
{
    LV_ASSERT_OBJ(obj, MY_CLASS);
    spin_t *spinbox = (spin_t *)obj;

    spinbox->value = v;
    spin_updatevalue(obj);
}

void spin_set_format(lv_obj_t *obj, char *format)
{
    LV_ASSERT_OBJ(obj, MY_CLASS);
    spin_t *spinbox = (spin_t *)obj;

    spinbox->format = format;
    spin_updatevalue(obj);
}

void spin_set_rollover(lv_obj_t *obj, bool rollover)
{
    LV_ASSERT_OBJ(obj, MY_CLASS);
    spin_t *spinbox = (spin_t *)obj;

    spinbox->rollover = rollover;
}

void spin_set_digit_format(lv_obj_t *obj, uint32_t digit_count, uint32_t sep_pos)
{
    LV_ASSERT_OBJ(obj, MY_CLASS);
    spin_t *spinbox = (spin_t *)obj;

    if (digit_count > SPIN_MAX_DIGIT_COUNT)
        digit_count = SPIN_MAX_DIGIT_COUNT;

    if (sep_pos >= digit_count)
        sep_pos = 0;

    if (digit_count < SPIN_MAX_DIGIT_COUNT)
    {
        const int64_t max_val = lv_pow(10, digit_count);
        if (spinbox->range_max > max_val - 1)
            spinbox->range_max = max_val - 1;
        if (spinbox->range_min < -max_val + 1)
            spinbox->range_min = -max_val + 1;
    }

    spinbox->digit_count = digit_count;
    spinbox->dec_point_pos = sep_pos;

    spin_updatevalue(obj);
}

void spin_set_step(lv_obj_t *obj, uint32_t step)
{
    LV_ASSERT_OBJ(obj, MY_CLASS);
    spin_t *spinbox = (spin_t *)obj;

    spinbox->step = step;
    spin_updatevalue(obj);
}

void spin_set_range(lv_obj_t *obj, int32_t range_min, int32_t range_max)
{
    LV_ASSERT_OBJ(obj, MY_CLASS);
    spin_t *spinbox = (spin_t *)obj;

    spinbox->range_max = range_max;
    spinbox->range_min = range_min;

    if (*spinbox->value > spinbox->range_max)
        *spinbox->value = spinbox->range_max;
    if (*spinbox->value < spinbox->range_min)
        *spinbox->value = spinbox->range_min;

    spin_updatevalue(obj);
}

void spin_set_cursor_pos(lv_obj_t *obj, uint32_t pos)
{
    LV_ASSERT_OBJ(obj, MY_CLASS);
    spin_t *spinbox = (spin_t *)obj;

    const int32_t step_limit = LV_MAX(spinbox->range_max, LV_ABS(spinbox->range_min));
    const int32_t new_step = lv_pow(10, pos);

    if (pos <= 0)
        spinbox->step = 1;
    else if (new_step <= step_limit)
        spinbox->step = new_step;

    spin_updatevalue(obj);
}

void spin_set_digit_step_direction(lv_obj_t *obj, lv_dir_t direction)
{
    LV_ASSERT_OBJ(obj, MY_CLASS);
    spin_t *spinbox = (spin_t *)obj;
    spinbox->digit_step_dir = direction;

    spin_updatevalue(obj);
}
/*=====================
 * Getter functions
 *====================*/

int32_t spin_get_value(lv_obj_t *obj)
{
    LV_ASSERT_OBJ(obj, MY_CLASS);
    spin_t *spinbox = (spin_t *)obj;

    return *spinbox->value;
}

int32_t spin_get_step(lv_obj_t *obj)
{
    LV_ASSERT_OBJ(obj, MY_CLASS);
    spin_t *spinbox = (spin_t *)obj;

    return spinbox->step;
}

/*=====================
 * Other functions
 *====================*/
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

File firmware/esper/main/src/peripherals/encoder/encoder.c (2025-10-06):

#include "freertos/FreeRTOS.h"
#include "esp_log.h"

#include <string.h>
#include <encoder.h>
#include <esp_idf_lib_helpers.h>
#include "esp_lvgl_port.h"

#define RE_A_GPIO 1
#define RE_B_GPIO 2
#define RE_BTN_GPIO 3

#define EV_QUEUE_LEN 32

static QueueHandle_t event_queue;

rotary_encoder_event_t e;

static rotary_encoder_t re;
int val = 0;

static const char *TAG = "Encoder";

void configEncoder(void)
{
    ESP_LOGI(TAG, "Started configEncoder");

    // Create event queue for rotary encoders
    event_queue = xQueueCreate(EV_QUEUE_LEN, sizeof(rotary_encoder_event_t));

    // Setup rotary encoder library
    ESP_ERROR_CHECK(rotary_encoder_init(event_queue));

    // Add one encoder
    memset(&re, 0, sizeof(rotary_encoder_t));
    re.pin_a = RE_A_GPIO;
    re.pin_b = RE_B_GPIO;
    re.pin_btn = RE_BTN_GPIO;
    ESP_ERROR_CHECK(rotary_encoder_add(&re));

    ESP_LOGI(TAG, "Initial value: %d", val);

    rotary_encoder_enable_acceleration(&re, 100);
    // rotary_encoder_disable_acceleration(&re);

    ESP_LOGI(TAG, "Finished configEncoder");
}

void getEncoderValue(int *ret_val, bool *pressed)

{
    while (xQueueReceive(event_queue, &e, 0))
    {
        ESP_LOGD(TAG, "Event: %d, diff: %ld", e.type, e.diff);
        switch (e.type)
        {
        case RE_ET_BTN_PRESSED:
            *pressed = true;
            break;
        case RE_ET_BTN_RELEASED:
            *pressed = false;
            break;
        case RE_ET_BTN_CLICKED:
            break;
        case RE_ET_BTN_LONG_PRESSED:
            break;
        case RE_ET_CHANGED:
            *ret_val -= e.diff;
            break;
        default:
            break;
        }
    }
}

int encoder_diff = 0;
bool encoder_pressed = false;
extern lv_indev_t *indev;

void updateEncoder()
{
    int old_encoder_diff = encoder_diff;
    bool old_encoder_pressed = encoder_pressed;
    getEncoderValue(&encoder_diff, &encoder_pressed);

    if (old_encoder_diff != encoder_diff || old_encoder_pressed != encoder_pressed || encoder_pressed)
    {

        lvgl_port_lock(0);
        lv_indev_read(indev);
        lvgl_port_unlock();
    }
}

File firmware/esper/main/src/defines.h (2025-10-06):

#define PWM0_GPIO       (12)
#define PWM0_CHANNEL    LEDC_CHANNEL_0
#define PWM1_GPIO       (11)
#define PWM1_CHANNEL    LEDC_CHANNEL_1

#define POT0_GPIO    7
#define POT1_GPIO    8
#define JACK0_GPIO    1
#define JACK1_GPIO    2
#define JACK2_GPIO    3
#define DIGI1_GPIO    13
#define DIGI2_GPIO    14

#define PROB_GPIO    13

#define TIMER_RESOLUTION 5000000 // 5MHz, 1 tick = 0.2us
#define SAMPRATE 48000
#define SAMPSTEP (1/SAMPRATE)
#define BLOCK_SIZE 24
#define FREQUENCY (SAMPRATE/BLOCK_SIZE)
#define TIMER_COUNT (TIMER_RESOLUTION/FREQUENCY)
#define TIMER_PERIOD_MICRO (1000000/FREQUENCY)
#define TIMER_PERIOD_SEC (1/FREQUENCY)

#define MAX_ADC_VAL 2605
#define MAX_ACTUAL_POTS_VAL 290
#define MAX_POTS_VAL 300
#define MAX_JACK_VAL 5430

#define COLOR_FG    lv_color_white()
#define COLOR_BG    lv_color_black()
